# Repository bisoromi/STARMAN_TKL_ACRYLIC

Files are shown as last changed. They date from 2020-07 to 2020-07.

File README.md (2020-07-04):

<p align="center">
  
</p>

# STARMAN ACRYLIC
Open source files for Starman acrylic version which is part of the "Starman" series of mechanical keyboards created by me. The Starman series features a stepless adjustable angle which starts from zero degrees and can go as high as you can feasibly make it (With a long enough rod). The angle is adjusted by turning the knob on top of the keyboard either clockwise to increase the angle, or counter-clockwise to lower the angle.

**Starman Acrylic** - Stacked Acrylic TKL  
**Starman** - Aluminum TKL  
**Starman Junior** - Aluminum 60%  

## Hardware

| Item | Quantity | Link | Details |
|---|---|---|---|
| Screws | 10 | https://www.mcmaster.com/96452A713/  |  M3*10mm |
| Standoffs | 10 | https://www.mcmaster.com/93090A659/  |  M3 |
| Threaded Insert | 1 | https://www.mcmaster.com/94180A387/  | Heat set is recommended |
| Knob/Thumb screw  | 1 | https://www.mcmaster.com/98014A665/  | M10. Thumb screw with a knob head |
| Threaded rod | 1 | https://www.mcmaster.com/94595A431/  |  M10. Only needed if you wish to explore other angles. Screws into knob head |
| Knob Head | 1 | https://www.mcmaster.com/98014A665/  | M10. Necessary if using your own threaded rod. Most styles should work |
| Feet | 1 | https://www.mcmaster.com/6120K41/ | M10 with threaded hole and rubber pad works best |
| Bumpons | 4 | https://www.digikey.com/product-detail/en/3m/SJ5001/3M162233-ND/ |  3M SJ5001/SJ5012. Fits 12.7mm diameter bumpons best |

## Supported PCBs
[Hineybush h87a](https://hineybush.com/products/h87a)  

## How To Use This Repo

`DXF_FILES/`  
In this directory you will find the .DXF files that are ready to be sent to a manufacturing service.

`PICS/`  
Just random pictures that might help visualize the design before opening any files.

`<PROJECT_NAME> <PROJECT_VERSION_NUMBER>.f3z`  
This is the Fusion360 file that will give you a full copy of the original design including the timeline history which allows you to edit any feature as needed! You can also use this file to export any other file formats that aren't in this repo. Go crazy!!!!  

<br />  
<br />  

<p align="center">
  
  <p align="center"><i>Photo by dq</i></p>
</p>
<br />  
<p align="center">
  
  <p align="center"><i>Photo by Yui</i></p>
</p>

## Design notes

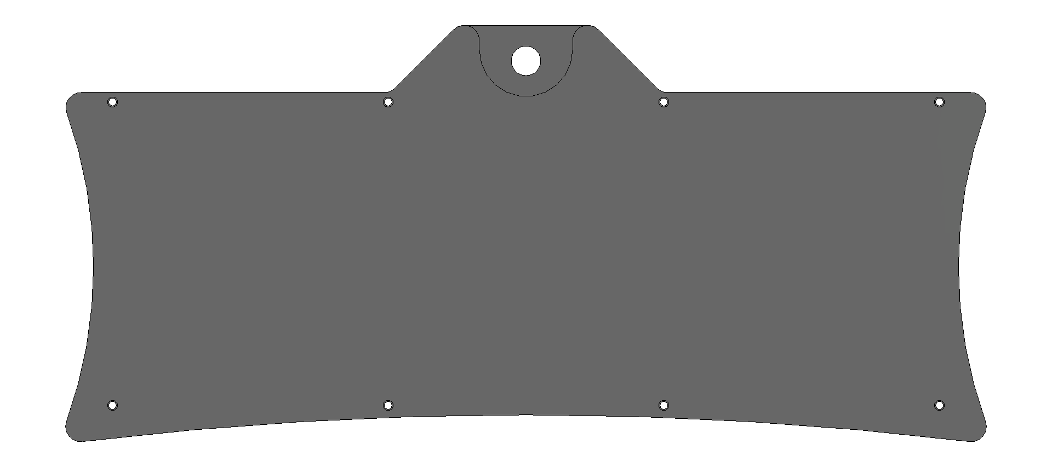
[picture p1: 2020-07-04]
PICS/Bottom.png

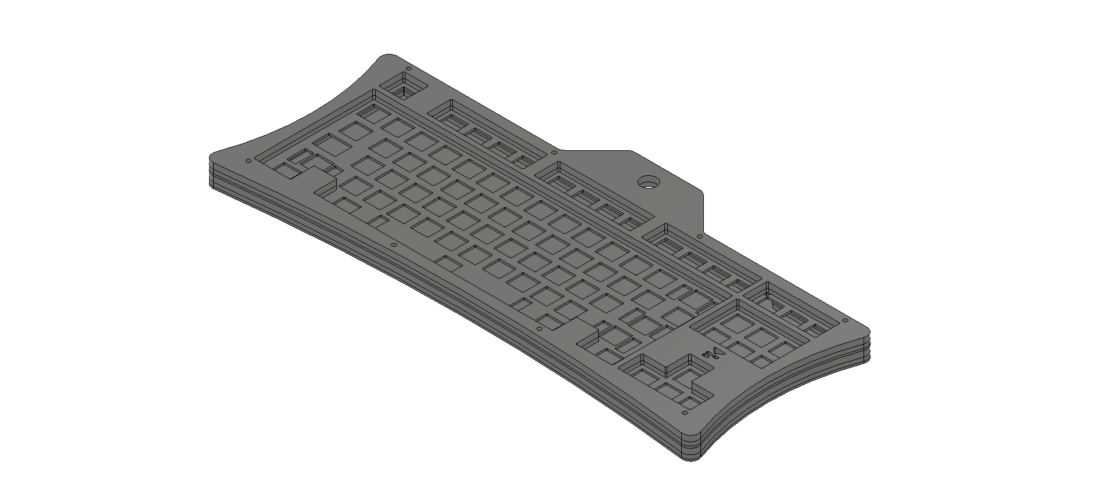
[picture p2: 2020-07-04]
PICS/STARMAN_ACRYLIC.png

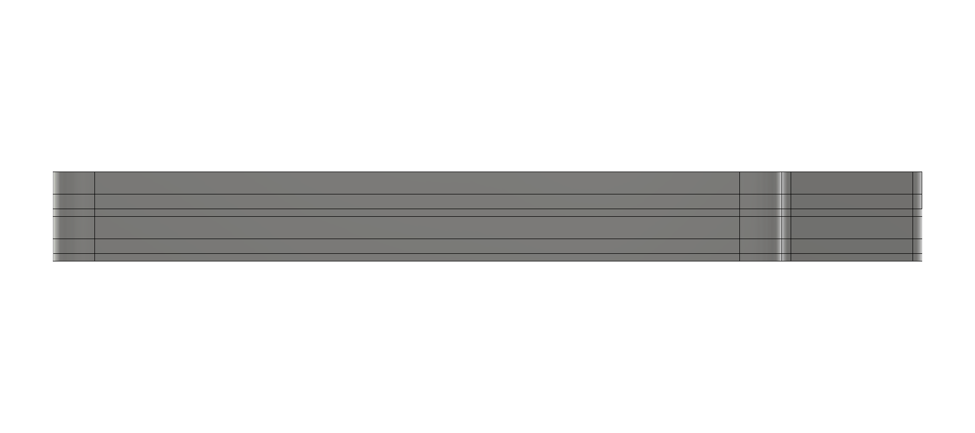
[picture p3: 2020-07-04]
PICS/Right.png

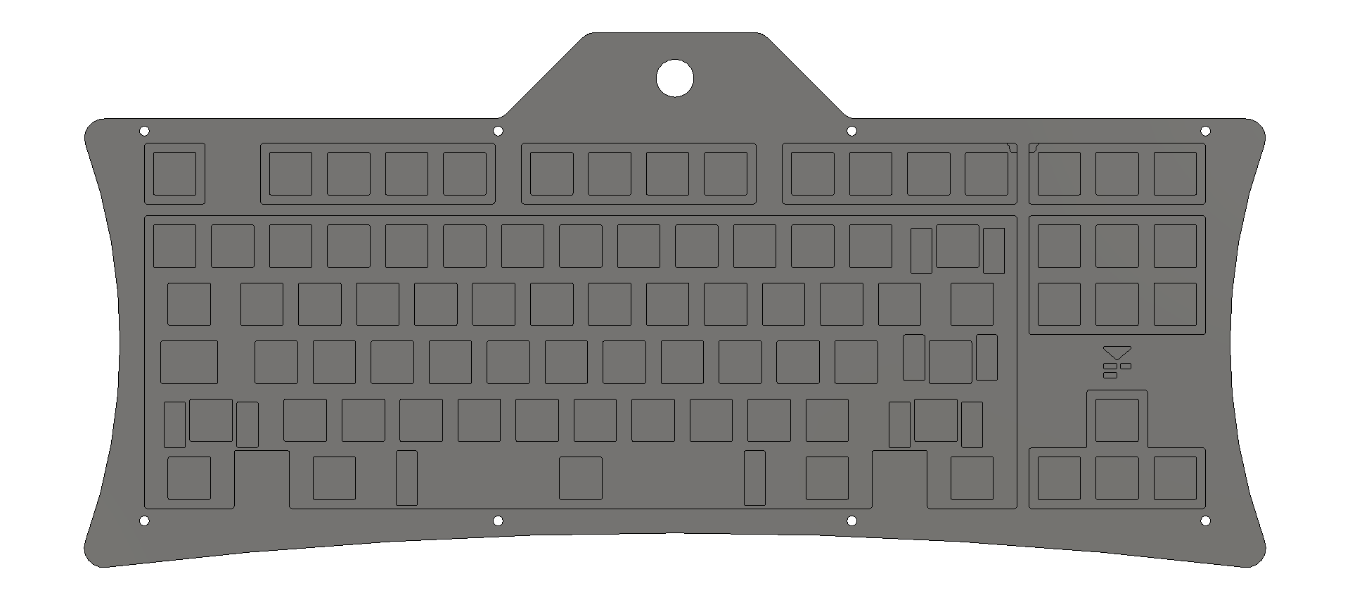
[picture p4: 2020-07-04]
PICS/Top.png

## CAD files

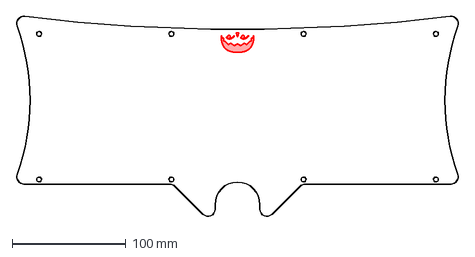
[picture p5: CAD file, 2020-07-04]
DXF_FILES/STARMAN_ACRYLIC_LAYER_6_BOTTOM.dxf
388.9 x 176.4 mm

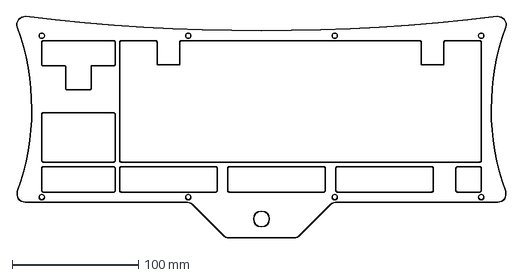
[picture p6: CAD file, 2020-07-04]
DXF_FILES/STARMAN_ACRYLIC_LAYER_2_TOP.dxf
388.9 x 175.9 mm

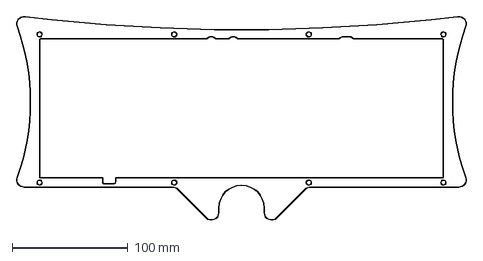
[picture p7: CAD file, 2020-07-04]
DXF_FILES/STARMAN_ACRYLIC_LAYER_5_MID.dxf
388.9 x 176.4 mm

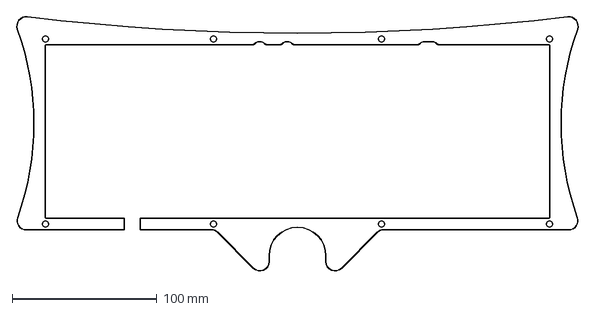
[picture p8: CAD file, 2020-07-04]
DXF_FILES/STARMAN_ACRYLIC_LAYER_4_MID.dxf
388.9 x 176.4 mm

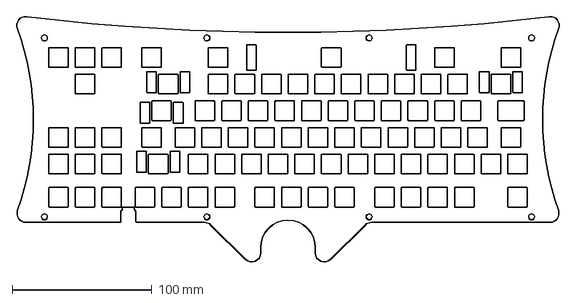
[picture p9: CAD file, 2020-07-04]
DXF_FILES/STARMAN_ACRYLIC_LAYER_3_PLATE.dxf
388.9 x 176.4 mm

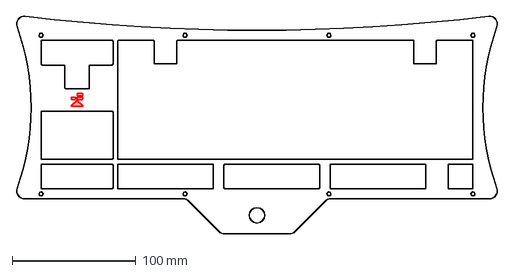
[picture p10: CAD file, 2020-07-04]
DXF_FILES/STARMAN_ACRYLIC_LAYER_1_TOP.dxf
388.9 x 175.9 mm

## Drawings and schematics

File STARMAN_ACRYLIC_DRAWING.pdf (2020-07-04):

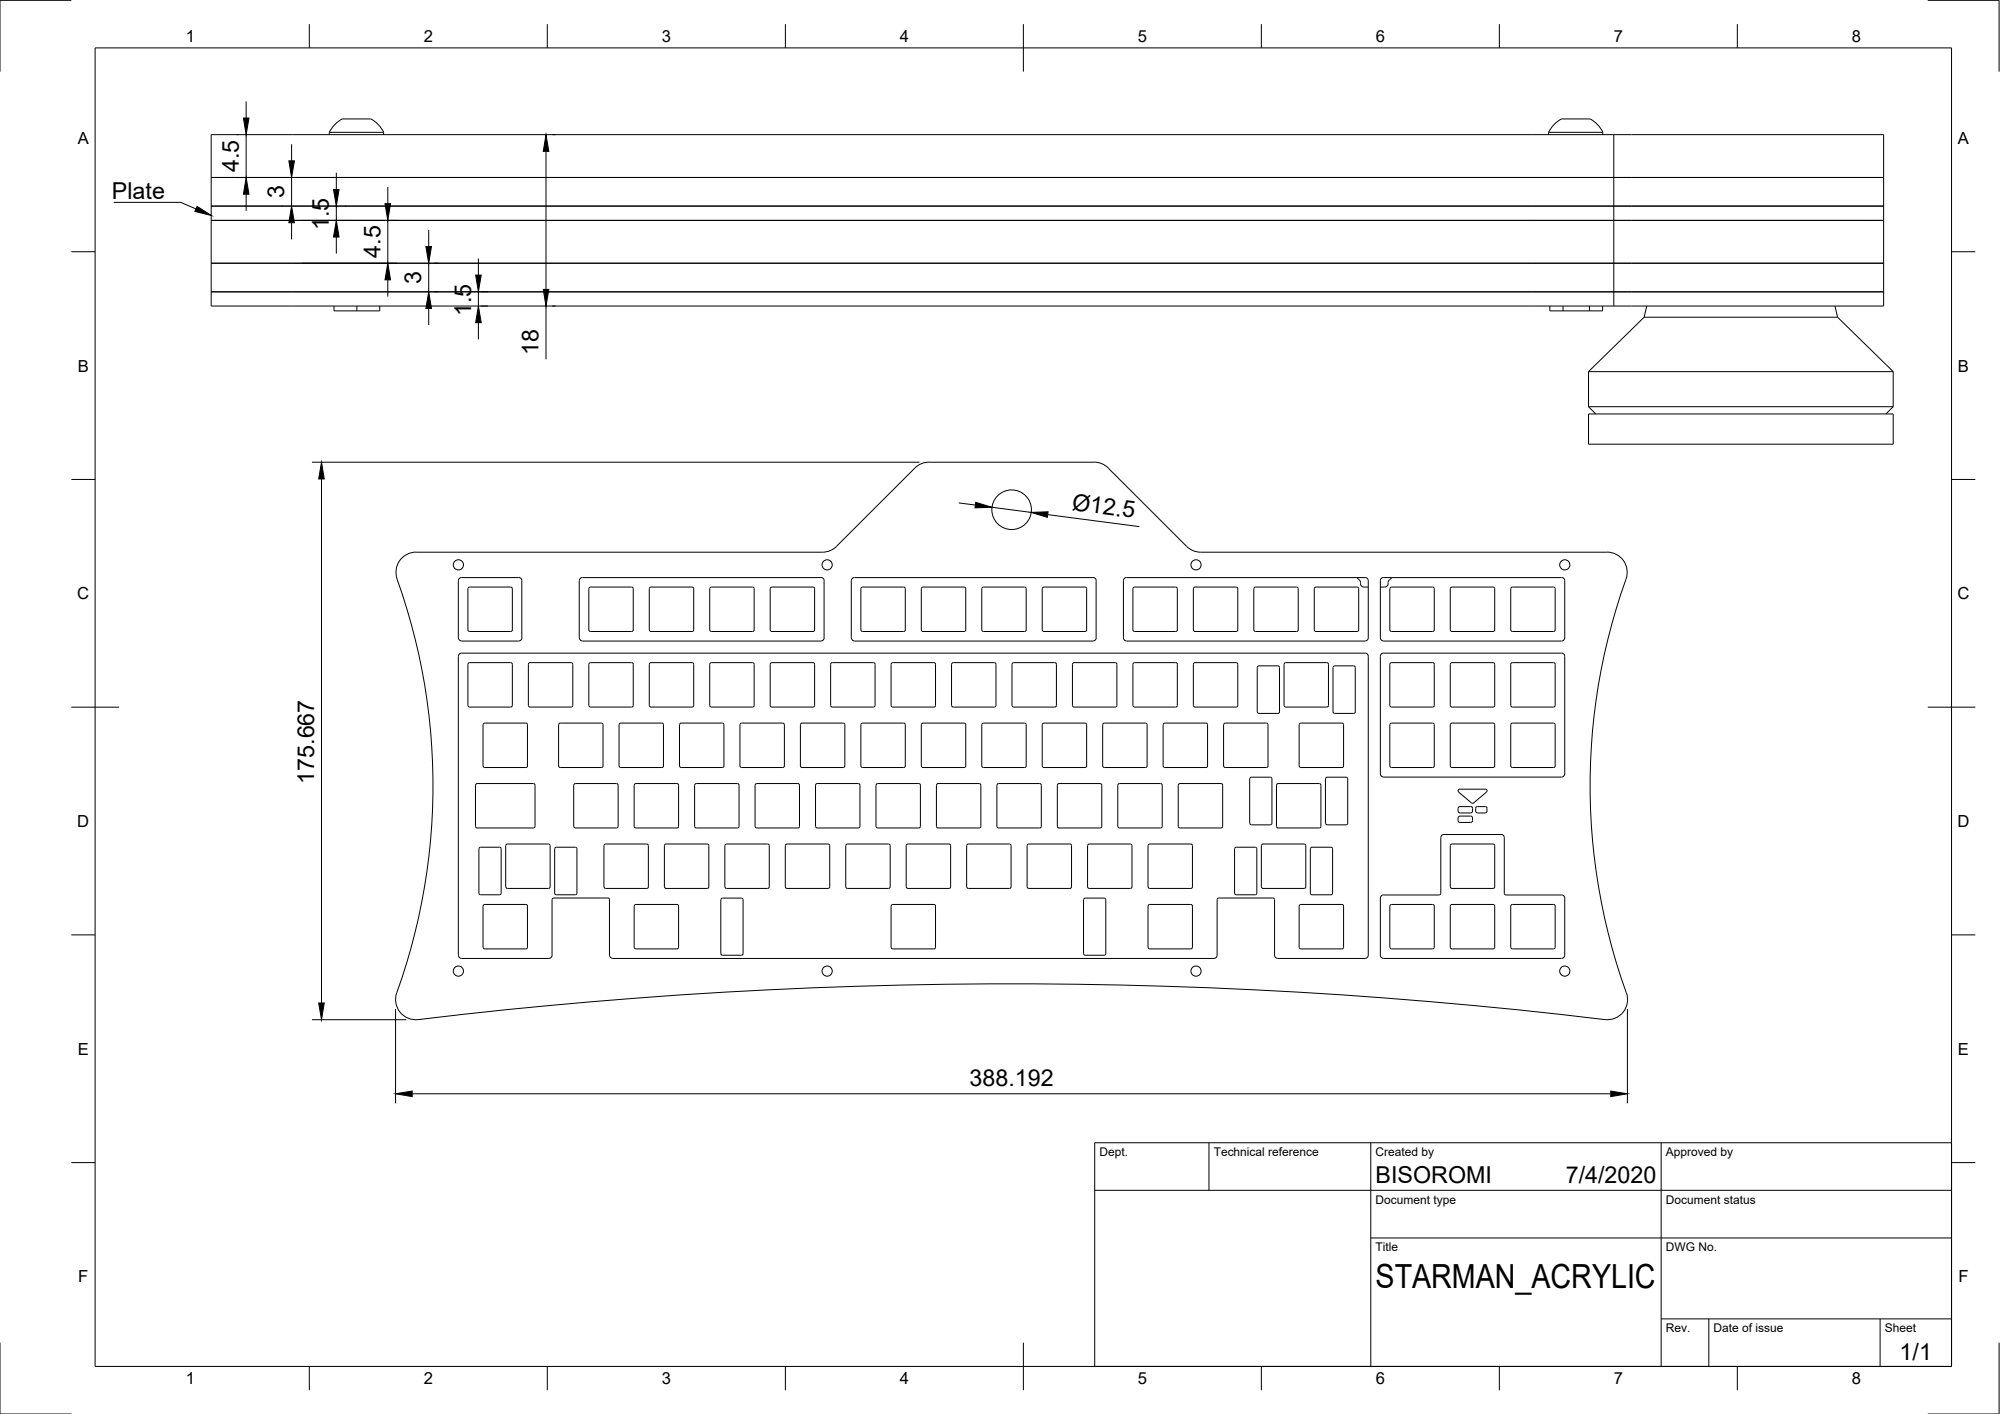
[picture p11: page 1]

Dept. | Technical reference | Created by BISOROMI 7/4/2020 | Approved by

Document type | Document status

Title STARMAN_ACRYLIC | DWG No.

Rev. | Date of issue | Sheet 1/1
